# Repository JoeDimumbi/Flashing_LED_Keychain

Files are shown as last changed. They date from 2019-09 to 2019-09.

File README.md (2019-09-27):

# **Lumkani Keychain**

This firmware is intended for use on the keychain hardware.

This repository contains the source code for fun project that blinks the LEDs on a keychain when the button is pressed

Keychain blinking LED project based on Microchip PIC16LF18326

## **Versions**

1. Install MPLAB-X IDE [v5.10](https://www.microchip.com/mplab/mplab-x-ide)
2. Install XC8 v[2.00](https://www.microchip.com/mplab/compilers)

## **Hardware Requirements**

    * PIC16LF18326 
    * PCB
	* Pushbutton
    * 3.3v CR2032 Battery
    * RED LED 0603
    * 17x GREEN LED 0603
    * 20x 1kΩ Resistor
	* 1x 1000PF 0603
	* 2x 0.1UF 0603

## **Description**

Used 1 PIC16LF18326 for controling the LEDs patterns. There are 1 Button allowing the circuit to be powered from the battery. 
When the button is pressed, the LEDs go on from the outside ring to the inside one.

Keychain_1Keychain_2

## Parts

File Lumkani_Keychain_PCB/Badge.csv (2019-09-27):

Id | Designator | Package | Quantity | Designation | Supplier and ref
1 | R14 | R_0603_1608Metric | 1 | 10
2 | D13,D1,D2,D3,D4,D5,D6,D7,D8,D9,D10,D11,D12,D14,D15,D16,D17,D18 | LED_0603_1608Metric_custom3 | 18 | LED_Small
3 | BT1 | BatteryHolder_Keystone_3034_1x20mm | 1 | Battery_Cell
4 | G*** | 142 | 1 | LOGO
5 | C1 | C_0603_1608Metric | 1 | 0.1
6 | C2 | C_0603_1608Metric | 1 | 0.1u
7 | C3 | C_0603_1608Metric | 1 | 0.001u
8 | R1,R2,R3,R4,R5,R6,R7,R8,R9,R10,R11,R12,R15,R16,R17,R18,R19,R20 | R_0603_1608Metric | 18 | 1k
9 | R13 | R_0603_1608Metric | 1 | 100
10 | SW1 | SW_SPST_B3U-1000P-B | 1 | SW_Push
11 | U1 | SOIC127P600X175-14N | 1 | PIC16LF18326T-I_SL
12 | TP1,TP2,TP3,TP4,TP5 | TestPoint_Pad_D1.0mm | 5 | TestPoint
13 | G*** | logo_512 | 1 | LOGO

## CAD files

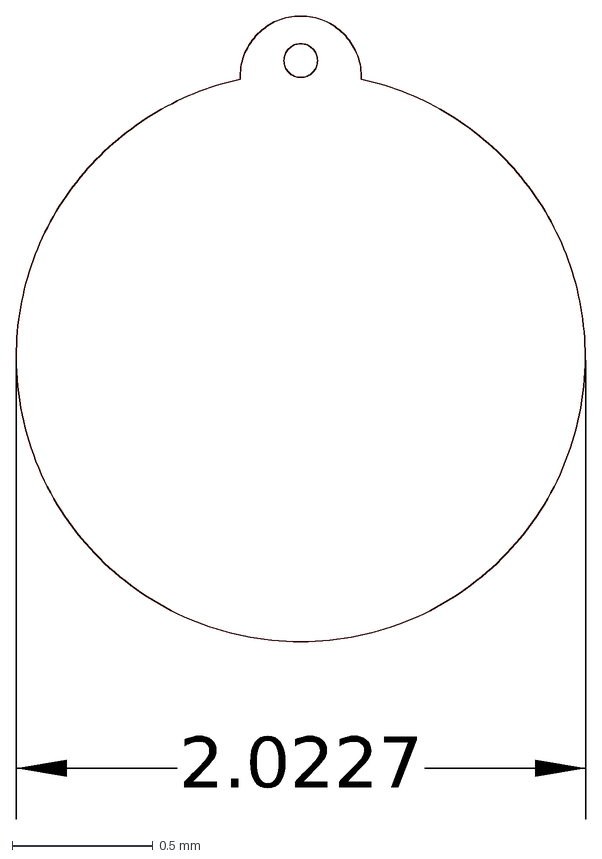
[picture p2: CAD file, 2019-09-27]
Lumkani_Keychain_PCB/Keyring.dxf
2.0227

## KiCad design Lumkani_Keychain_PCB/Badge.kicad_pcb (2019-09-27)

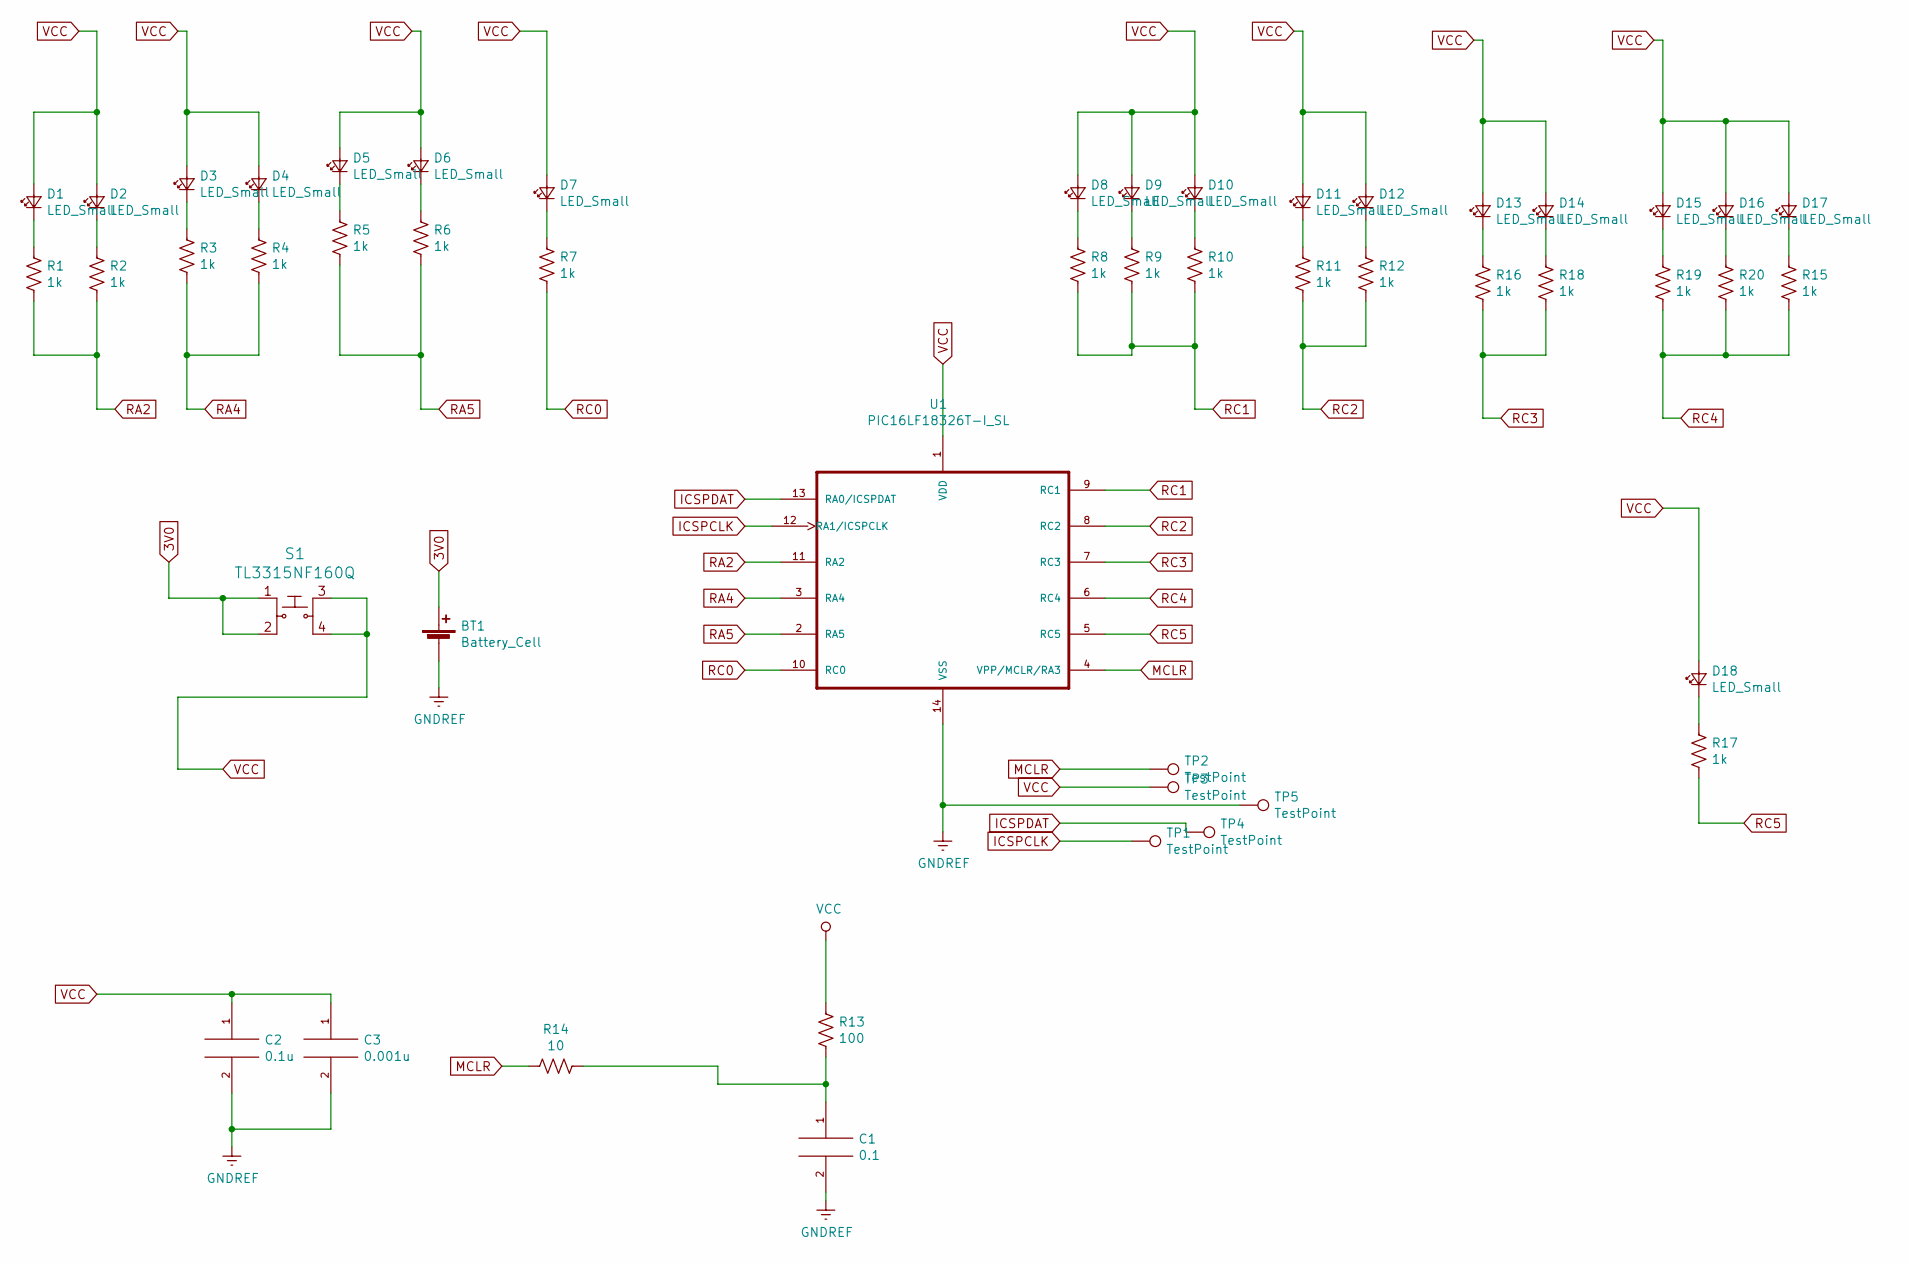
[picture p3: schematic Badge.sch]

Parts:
BT1: Battery_Cell; BatteryHolder_Keystone_3034_1x20mm
C1: 0.1; C_0603_1608Metric
C2: 0.1u; C_0603_1608Metric
C3: 0.001u; C_0603_1608Metric
D1, D2, D3, D4, D5, D6, D7, D8, D9, D10, D11, D12, D13, D14, D15, D16, D17, D18: LED_Small; LED_0603_1608Metric_custom3
R1, R2, R3, R4, R5, R6, R7, R8, R9, R10, R11, R12, R15, R16, R17, R18, R19, R20: 1k; R_0603_1608Metric
R13: 100; R_0603_1608Metric
R14: 10; R_0603_1608Metric
S1: TL3315NF160Q; Switch_Tactile_SMD_4.5x4.5mm_TL3315NF160Q; MPN TL3315NF160Q; Digi-Key_PN EG4621CT-ND
TP1, TP2, TP3, TP4, TP5: TestPoint; TestPoint_Pad_D1.0mm
U1: PIC16LF18326T-I_SL; SOIC127P600X175-14N

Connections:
3V0: BT1.1 (+), S1.1, S1.2
GNDREF: BT1.2 (-), C1.2, C2.2, C3.2, TP5.1, U1.14 (VSS)
ICSPCLK: TP1.1, U1.12 (RA1/ICSPCLK)
ICSPDAT: TP4.1, U1.13 (RA0/ICSPDAT)
MCLR: R14.2, TP2.1, U1.4 (VPP/MCLR/RA3)
unnamed: C1.1, R13.2, R14.1
unnamed: D1.1 (K), R1.1
unnamed: D2.1 (K), R2.1
unnamed: D3.1 (K), R3.1
unnamed: D4.1 (K), R4.1
unnamed: D5.1 (K), R5.1
unnamed: D6.1 (K), R6.1
unnamed: D7.1 (K), R7.1
unnamed: D8.1 (K), R8.1
unnamed: D9.1 (K), R9.1
unnamed: D10.1 (K), R10.1
unnamed: D11.1 (K), R11.1
unnamed: D12.1 (K), R12.1
unnamed: D13.1 (K), R16.1
unnamed: D14.1 (K), R18.1
unnamed: D15.1 (K), R19.1
unnamed: D16.1 (K), R20.1
unnamed: D17.1 (K), R15.1
unnamed: D18.1 (K), R17.1
RA2: R1.2, R2.2, U1.11 (RA2)
RA4: R3.2, R4.2, U1.3 (RA4)
RA5: R5.2, R6.2, U1.2 (RA5)
RC0: R7.2, U1.10 (RC0)
RC1: R8.2, R9.2, R10.2, U1.9 (RC1)
RC2: R11.2, R12.2, U1.8 (RC2)
RC3: R16.2, R18.2, U1.7 (RC3)
RC4: R15.2, R19.2, R20.2, U1.6 (RC4)
RC5: R17.2, U1.5 (RC5)
VCC: C2.1, C3.1, D1.2 (A), D2.2 (A), D3.2 (A), D4.2 (A), D5.2 (A), D6.2 (A), D7.2 (A), D8.2 (A), D9.2 (A), D10.2 (A), D11.2 (A), D12.2 (A), D13.2 (A), D14.2 (A), D15.2 (A), D16.2 (A), D17.2 (A), D18.2 (A), R13.1, S1.3, S1.4, TP3.1, U1.1 (VDD)

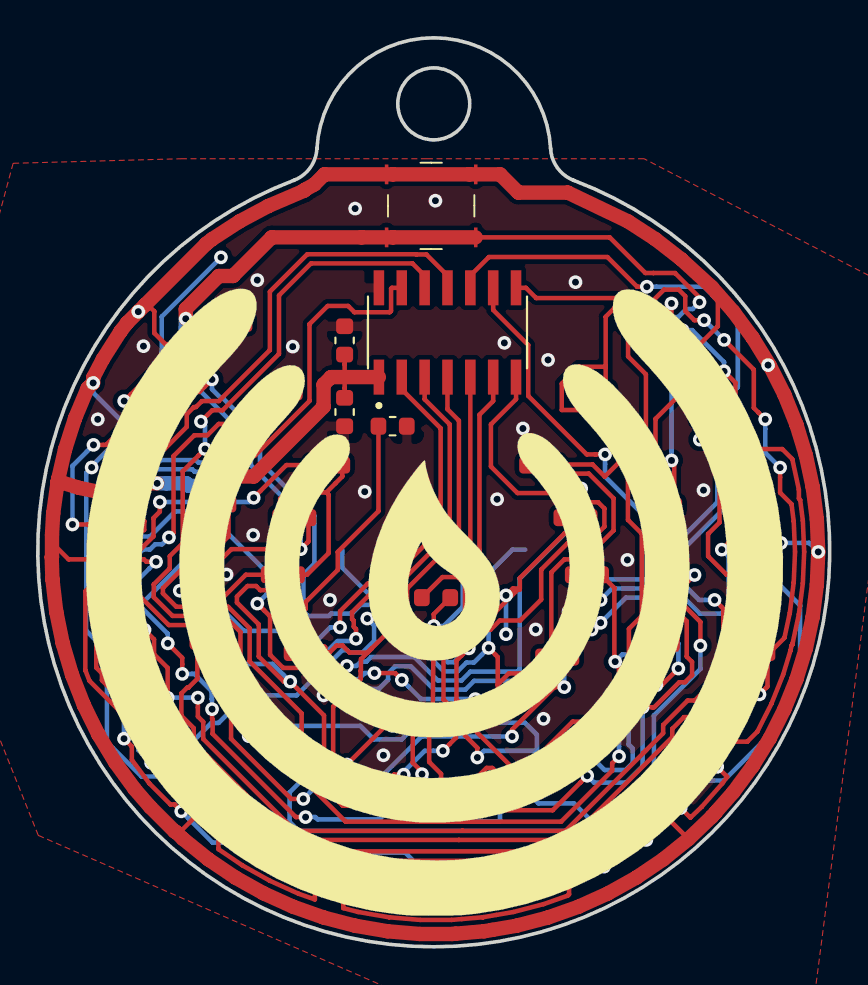
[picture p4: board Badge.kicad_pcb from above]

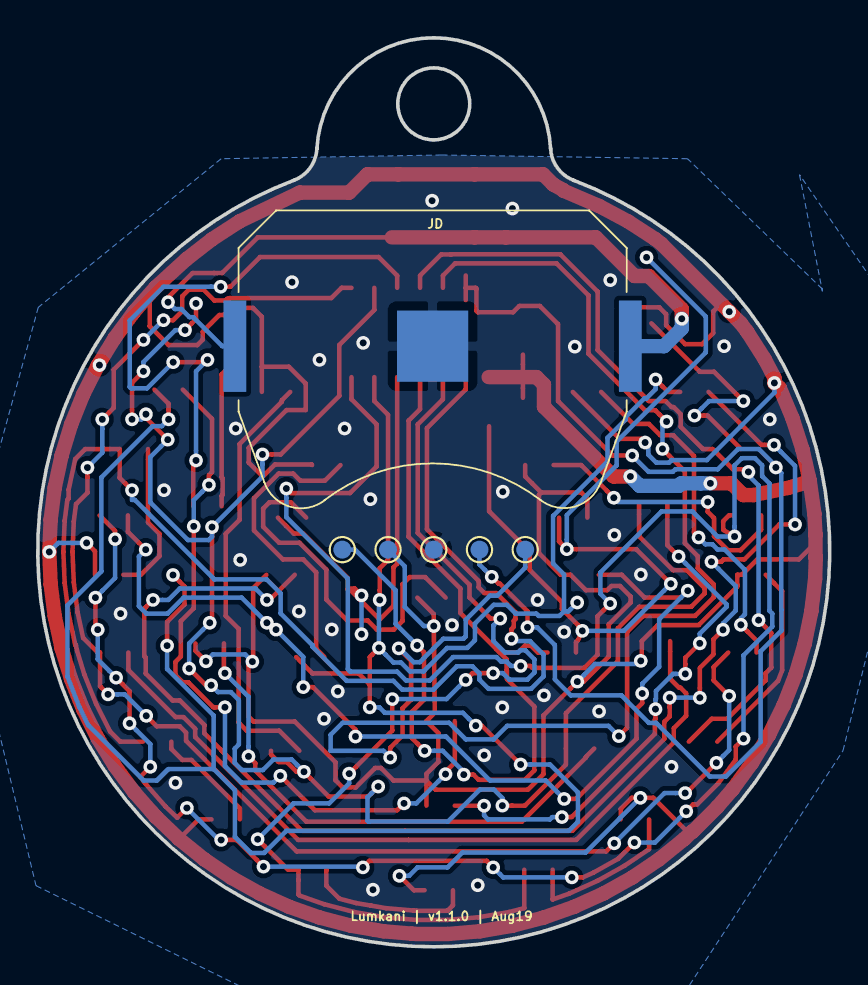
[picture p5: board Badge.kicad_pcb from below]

Board: 2 copper layers, 44.0 x 50.5 mm, 49 parts (6 on the bottom side), 34 nets.

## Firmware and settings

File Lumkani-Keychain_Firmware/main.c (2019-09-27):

// <editor-fold defaultstate="collapsed" desc="Description">
/** @file main.c
 *
 * @brief Firmware for the Lumkani Keychain
 *
 * @par
 * Author: Lumkani Team
 * Started on Apr 5, 2018
 */

#define _SUPPRESS_PLIB_WARNING
// </editor-fold>

// <editor-fold defaultstate="collapsed" desc="Includes">

#include <stdint.h>
#include <stdio.h>
#include "config.h"
#include "pinmap.h"
#include "hardware.h"
#include "display.h"

// </editor-fold>

// <editor-fold defaultstate="collapsed" desc="Global Variables">

// </editor-fold>

void main (void)
{
    oscillator.wait_for_startup_clock_ready();
    watchdog.initialize();
    display.initialize();
    while(1)
    {
        display.pattern_scroll_out(1);
        __delay_ms(100);
        display.pattern_scroll_in(1);
    }
        watchdog.clear();
}

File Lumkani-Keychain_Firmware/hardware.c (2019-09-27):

/*
 * File:   hardware.c
 * Author: Lumkani Team
 *
 * Created on 1 September 2018
 */

// <editor-fold defaultstate="collapsed" desc="Includes">

#include "hardware.h"
#include <xc.h>

// </editor-fold>

// <editor-fold defaultstate="collapsed" desc="Pragma">

// CONFIG1 register

#pragma config FEXTOSC  = OFF                                                   // External oscillator disabled.
#pragma config RSTOSC   = LFINT                                                 // Power-up default value for COSC (LFINT = 31kHz).
#pragma config CLKOUTEN = OFF                                                   // CLKOUT function disabled.
#pragma config CSWEN    = ON                                                   // Cannot change clock source in user software (Cannot be changed from RSTOSC).

// CONFIG2 register

#pragma config MCLRE    = ON                                                    // Pin is set to MCLR function.
#pragma config PWRTE    = OFF                                                   // Power-up timer disabled.
#pragma config WDTE     = ON                                                    // Watchdog enabled.
#pragma config BOREN    = OFF                                                   // Brown-out reset disabled.

// CONFIG3 register

#pragma config LVP      = OFF                                                   // Low voltage programming disabled.

// CONFIG4 register

#pragma config CP       = ON                                                    // Program memory code protection enabled.
#pragma config CPD      = ON                                                    // Data memory code protection enabled.

// </editor-fold>

// <editor-fold defaultstate="collapsed" desc="Oscillator">

#define _CLOCK_SWITCH_TIMEOUT_COUNT 10

static clock_source_t get_clock_source (void);
static void wait_for_startup_clock_ready (void);
static boolean_state_t switch_clock (clock_mode_t* clock);
static void set_clock_to_pin (pin_t* pin);

oscillator_interface_t oscillator = {
    .get_clock_source = get_clock_source,
    .wait_for_startup_clock_ready = wait_for_startup_clock_ready,
    .switch_clock = switch_clock,
    .set_clock_to_pin = set_clock_to_pin
};

static clock_source_t get_clock_source (void)
{    
    return OSCCON2bits.COSC;
}

static void wait_for_startup_clock_ready (void)
{
    while (!OSCCON3bits.ORDY)
    {
        asm("NOP");
    }
}

static boolean_state_t switch_clock (clock_mode_t* clock)
{
    uint8_t timeout_count = 0;
    boolean_state_t b_result = FALSE;
    clock_source_t old_clock_source = oscillator.get_clock_source();
    
    OSCCON3bits.CSWHOLD = 1;                                                    // Keep using old clock until this bit is cleared.
    OSCCON1bits.NOSC = clock->clock_source;
    OSCCON1bits.NDIV = clock->clock_divider;
    
    while (!(OSCCON3bits.NOSCR) && (timeout_count < _CLOCK_SWITCH_TIMEOUT_COUNT))
    {
        mDELAY_US(1);
        timeout_count++;
    }
    
    OSCCON3bits.CSWHOLD = 0;                                                    // Allow clock switch.
    
    b_result = clock->clock_source != old_clock_source;
    
    return b_result;
}

static void set_clock_to_pin (pin_t* pin)
{
    pin_mode(pin, DIGITAL_OUTPUT_PUSH_PULL);
    output_pps(pin, OUTPUT_PPS_CLKR);
    
    PMD0bits.CLKRMD = 0;                                                        // Ensure reference clock output module is powered.
    CLKRCONbits.CLKRDC = 0b10;                                                  // Set duty cycle to 50%.
    CLKRCONbits.CLKRDIV = 0;                                                    // No clock divide.
    CLKRCONbits.CLKREN = 1;
    
    // Note: Ensure CLKOUTEN is set in Pragma.
}

// </editor-fold>

// <editor-fold defaultstate="collapsed" desc="GPIO">

#define _PORTxPORT_OFFSET                   0x000
#define _PORTxTRIS_OFFSET                   0x080                          
#define _PORTxLAT_OFFSET                    0x100
#define _PORTxANSEL_OFFSET                  0x180
#define _PORTxWPU_OFFSET                    0x200
#define _PORTxODCON_OFFSET                  0x280

gpio_interface_t gpio = {
    .mode = pin_mode,
    .write = write_pin,
    .set = set_pin,
    .reset = reset_pin,
    .toggle = toggle_pin,
    .output_pps = output_pps
};
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

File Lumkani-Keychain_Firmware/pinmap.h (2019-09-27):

/* 
 * File:   pinmap.h
 * Author: Lumkani Team
 * Created on 1 September 2018
 */

#ifndef PINMAP_H
#define	PINMAP_H

// <editor-fold defaultstate="collapsed" desc="Includes">

#include <stdint.h>
#include <xc.h>

// </editor-fold>

/* Base Addresses for Peripherals */
#define _PORTA_BASE_ADDRESS                      0x00C
#define _PORTB_BASE_ADDRESS                      0x00D
#define _PORTC_BASE_ADDRESS                      0x00E

// <editor-fold defaultstate="collapsed" desc="PPS Definitions">

#define INPUT_PPS_INTPPS         (0xE10)
#define INPUT_PPS_T0CKIPPS       (0xE11)
#define INPUT_PPS_T1CKIPPS       (0xE12)
#define INPUT_PPS_T1GPPS         (0xE13)
#define INPUT_PPS_T3CKIPPS       (0xE2C)
#define INPUT_PPS_T3GPPS         (0xE2D)
#define INPUT_PPS_T5CKIPPS       (0xE2E)
#define INPUT_PPS_T5GPPS         (0xE2F)
#define INPUT_PPS_CCP1PPS        (0xE14)
#define INPUT_PPS_CCP2PPS        (0xE15)
#define INPUT_PPS_CCP3PPS        (0xE16)
#define INPUT_PPS_CCP4PPS        (0xE17)
#define INPUT_PPS_CWG1PPS        (0xE18)
#define INPUT_PPS_CWG2PPS        (0xE19)
#define INPUT_PPS_MDCIN1PPS      (0xE1A)
#define INPUT_PPS_MDCIN2PPS      (0xE1B)
#define INPUT_PPS_MDMINPPS       (0xE1C)
#define INPUT_PPS_SSP1CLKPPS     (0xE20)
#define INPUT_PPS_SSP1DATPPS     (0xE21)
#define INPUT_PPS_SSP1SSPPS      (0xE22)
#define INPUT_PPS_SSP2CLKPPS     (0xE1D)
#define INPUT_PPS_SSP2DATPPS     (0xE1E)
#define INPUT_PPS_SSP2SSPPS      (0xE1F)
#define INPUT_PPS_RXPPS          (0xE24)
#define INPUT_PPS_TXPPS          (0xE25)
#define INPUT_PPS_CLCIN0PPS      (0xE28)
#define INPUT_PPS_CLCIN1PPS      (0xE29)
#define INPUT_PPS_CLCIN2PPS      (0xE2A)
#define INPUT_PPS_CLCIN3PPS      (0xE2B)

#define INPUT_PPS_A0 			 0b00000
#define INPUT_PPS_A1 			 0b00001
#define INPUT_PPS_A2 			 0b00010
#define INPUT_PPS_A3 			 0b00011
#define INPUT_PPS_A4 			 0b00100
#define INPUT_PPS_A5             0b00101
#define INPUT_PPS_B4             0b01100
#define INPUT_PPS_B5             0b01101
#define INPUT_PPS_B6             0b01110
#define INPUT_PPS_B7             0b01111
#define INPUT_PPS_C0 			 0b10000
#define INPUT_PPS_C1 			 0b10001
#define INPUT_PPS_C2 			 0b10010
#define INPUT_PPS_C3 			 0b10011
#define INPUT_PPS_C4 			 0b10100
#define INPUT_PPS_C5 			 0b10101
#define INPUT_PPS_C6 			 0b10110
#define INPUT_PPS_C7 			 0b10111

#define OUTPUT_PPS_A0  			 (0xE90)
#define OUTPUT_PPS_A1  			 (0xE91)
#define OUTPUT_PPS_A2  			 (0xE92)
#define OUTPUT_PPS_A3  			 0                                              // MCLR pin not included in PPS.
#define OUTPUT_PPS_A4  			 (0xE94)
#define OUTPUT_PPS_A5            (0xE95)
#define OUTPUT_PPS_B4            (0xE9C)
#define OUTPUT_PPS_B5            (0xE9D)
#define OUTPUT_PPS_B6            (0xE9E)
#define OUTPUT_PPS_B7            (0xE9F)
#define OUTPUT_PPS_C0  			 (0xEA0)
#define OUTPUT_PPS_C1  			 (0xEA1)
#define OUTPUT_PPS_C2  			 (0xEA2)
#define OUTPUT_PPS_C3  			 (0xEA3)
#define OUTPUT_PPS_C4  			 (0xEA4)
#define OUTPUT_PPS_C5  			 (0xEA5)
#define OUTPUT_PPS_C6 			 (0xEA6)
#define OUTPUT_PPS_C7 			 (0xEA7)

#define OUTPUT_PPS_DSM           0b11111
#define OUTPUT_PPS_CLKR          0b11110
#define OUTPUT_PPS_NCO1          0b11101
#define OUTPUT_PPS_TMR0          0b11100
#define OUTPUT_PPS_SDO2_SDA2     0b11011
#define OUTPUT_PPS_SCK2_SCL2     0b11010
#define OUTPUT_PPS_SDO1_SDA1     0b11001
#define OUTPUT_PPS_SCK1_SCL1     0b11000
#define OUTPUT_PPS_CMP2          0b10111
#define OUTPUT_PPS_CMP1          0b10110
#define OUTPUT_PPS_DT            0b10101
#define OUTPUT_PPS_TX_CK         0b10100
#define OUTPUT_PPS_CWG2D         0b10011
#define OUTPUT_PPS_CWG2C         0b10010
#define OUTPUT_PPS_CWG2B         0b10001
#define OUTPUT_PPS_CWG2A         0b10000
#define OUTPUT_PPS_CCP4          0b01111
#define OUTPUT_PPS_CCP3          0b01110
#define OUTPUT_PPS_CCP2          0b01101
#define OUTPUT_PPS_CCP1          0b01100
#define OUTPUT_PPS_CWG1D         0b01011
#define OUTPUT_PPS_CWG1C         0b01010
#define OUTPUT_PPS_CWG1B         0b01001
#define OUTPUT_PPS_CWG1A         0b01000
#define OUTPUT_PPS_CLC4OUT       0b00111
#define OUTPUT_PPS_CLC3OUT       0b00110
#define OUTPUT_PPS_CLC2OUT       0b00101
#define OUTPUT_PPS_CLC1OUT       0b00100
#define OUTPUT_PPS_PWM6          0b00011
#define OUTPUT_PPS_PWM5          0b00010

// </editor-fold>

// <editor-fold defaultstate="collapsed" desc="ADC Channels">
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
